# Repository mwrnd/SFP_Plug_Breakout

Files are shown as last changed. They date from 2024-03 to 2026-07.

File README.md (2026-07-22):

**Work-in-Progress** - [First Revision gerbers being tested](https://github.com/mwrnd/SFP_Plug_Breakout/releases/tag/v0.1-alpha).

# SFP_Plug_Breakout

Pluggable [SFP (SFF INF-8074i)](https://members.snia.org/document/dl/26184) and [SFP+ (SFF-8432)](https://members.snia.org/document/dl/25892) Module Breakout for developing SFP modules. PCB must be manufactured with a **1.0mm** thickness.

Similar Projects: [SFP-Breakout-Board](https://github.com/aewallin/SFP-Breakout-Board/tree/df46707f1ecbe9b7fed1791247dec31a45b60560), [SFP_BreakoutBoard](https://github.com/kingyoPiyo/SFP_BreakoutBoard), [SFP-Loopback-Board](https://github.com/aewallin/SFP-Loopback-Board), and [Sfp-breakout](https://osmocom.org/projects/misc-hardware/wiki/Sfp-breakout)(*osmocom.org*).

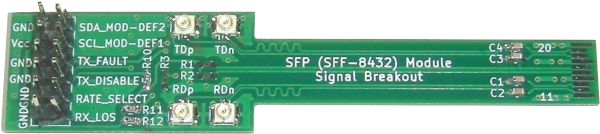
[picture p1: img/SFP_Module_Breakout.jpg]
SFP Module Breakout


One trivial use is an [SFP Loopback](https://www.fs.com/products/109371.html):

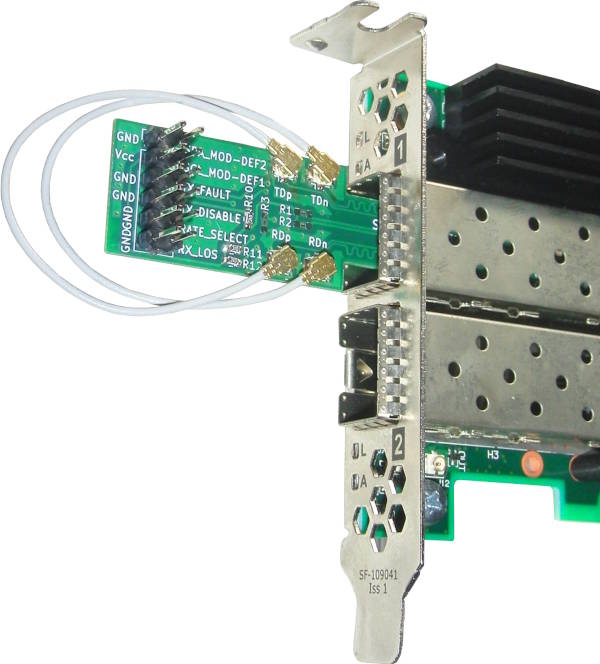
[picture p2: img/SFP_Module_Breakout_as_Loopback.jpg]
SFP Module Breakout as Loopback


## PCB Layout

Differential pair parameters were calculated based on a **board thickness of 1.0mm**.

SFP Plug Module Breakout PCB Layout

## Schematic

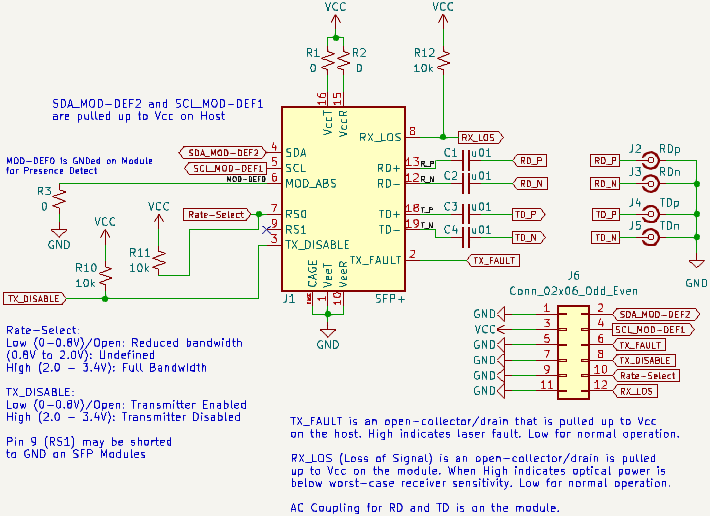
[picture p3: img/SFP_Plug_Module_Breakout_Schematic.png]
SFP Plug Module Breakout Schematic


The 0.1" Header is designed to accept jumpers for the **TX_FAULT**, **RX_LOS**, **TX_DISABLE**, and optionally **Rate-Select** signals.

**TX_FAULT**, **RX_LOS**, and **TX_DISABLE** jumpers need to be mounted for normal operation. These signals are pulled up to Vcc with 10k resistors but are Active-Low.

## Bill Of Materials

I have been testing with general purpose capacitors for the RX and TX DC-Blocking capacitors (C1, C2, C3, C4) but at <10Gbps bitrates. Capacitors will need to be sized smaller, 0402 or even 0201, and more effort would need to go into their selection for high bitrates. Look for [capacitors designed for high-frequency](https://www.digikey.ca/en/products/detail/passive-plus/0402BB104KW500/19186629).

| Designator(s) | Part Number | Quantity | Value | Footprint | Availability |
| --- | --- | --- | --- | --- | --- |
| C1, C2, C3, C4  | GRM1885C1H103JA01D  | 4 | 0.01uF  | Capacitor_SMD:C_0603_1608Metric  | [DigiKey](https://www.digikey.ca/en/products/detail/murata-electronics/GRM1885C1H103JA01D/4421555) |
| R1, R2, R3 | RMCF0603ZT0R00 | 3 | 0-Ohm | Resistor_SMD:R_0603_1608Metric | [DigiKey](https://www.digikey.ca/en/products/detail/stackpole-electronics-inc/RMCF0603ZT0R00/1756908)  |
| R10, R11, R12 | RNCF0603DTE10K0 | 3 | 10k-Ohm | Resistor_SMD:R_0603_1608Metric | [DigiKey](https://www.digikey.ca/en/products/detail/stackpole-electronics-inc/RNCF0603DTE10K0/1708145) |
| J6 | PH2-12-UA | 1 | N/A | Conn_02x06 | [DigiKey](https://www.digikey.ca/en/products/detail/adam-tech/PH2-12-UA/9830397) |
| J2, J3, J4, J5  | CONUFL001-SMD-T | 4 | N/A | U.FL_w_Label:U.FL_Hirose_w_Label | [DigiKey](https://www.digikey.ca/en/products/detail/te-connectivity-linx/CONUFL001-SMD-T/7427732) |
| None | QPC02SXGN-RC | 4 | N/A | 1x2 0.1" Jumper | [DigiKey](https://www.digikey.ca/en/products/detail/sullins-connector-solutions/QPC02SXGN-RC/2618262)  |
| U.FL-to-U.FL | 2015698-2 | 2 | N/A | None - Optional Part for Testing | [DigiKey](https://www.digikey.ca/en/products/detail/te-connectivity-amp-connectors/2015698-2/1249186)  |

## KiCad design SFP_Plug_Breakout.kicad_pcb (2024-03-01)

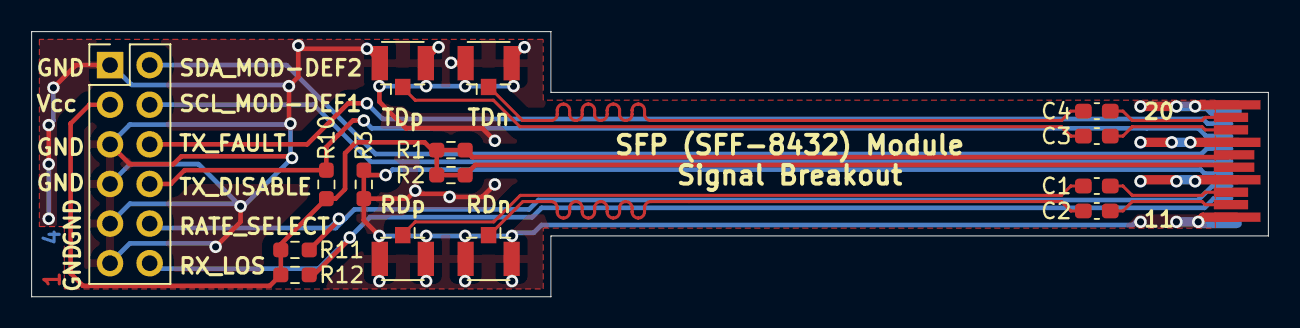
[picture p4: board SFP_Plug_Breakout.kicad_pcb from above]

Board: 4 copper layers, 79.3 x 17.0 mm, 16 parts (0 on the bottom side), 17 nets.

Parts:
C1, C2, C3, C4: u01; C_0603_1608Metric_Pad1.08x0.95mm_HandSolder
J1: SFP+; SFP_Plug
J2: RDp; U.FL_Hirose_w_Label
J3: RDn; U.FL_Hirose_w_Label
J4: TDp; U.FL_Hirose_w_Label
J5: TDn; U.FL_Hirose_w_Label
J6: Conn_02x06_Odd_Even; PinHeader_2x06_P2.54mm_Vertical
R1, R2, R3: 0; R_0603_1608Metric_Pad0.98x0.95mm_HandSolder
R10, R11, R12: 10k; R_0603_1608Metric_Pad0.98x0.95mm_HandSolder

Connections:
/MOD-DEF0: J1.6 (MOD_ABS), R3.1
/R_N: C2.1, J1.12 (RD-)
/R_P: C1.1, J1.13 (RD+)
/T_N: C4.1, J1.19 (TD-)
/T_P: C3.1, J1.18 (TD+)
GND: J1.1 (VeeT), J1.10 (VeeR), J1.11 (VeeR), J1.14 (VeeR), J1.17 (VeeT), J1.20 (VeeT), J2.2 (Ext), J3.2 (Ext), J4.2 (Ext), J5.2 (Ext), J6.1, J6.5, J6.7, J6.9, J6.11, R3.2
RD_N: C2.2, J3.1 (In)
RD_P: C1.2, J2.1 (In)
RX_LOS: J1.8 (RX_LOS), J6.12, R12.2
Rate-Select: J1.7 (RS0), J6.10, R11.2
SCL_MOD-DEF1: J1.5 (SCL), J6.4
SDA_MOD-DEF2: J1.4 (SDA), J6.2
TD_N: C4.2, J5.1 (In)
TD_P: C3.2, J4.1 (In)
TX_DISABLE: J1.3 (TX_DISABLE), J6.8, R10.2
TX_FAULT: J1.2 (TX_FAULT), J6.6
VCC: J1.15 (VccR), J1.16 (VccT), J6.3, R1.1, R1.2, R2.1, R2.2, R10.1, R11.1, R12.1

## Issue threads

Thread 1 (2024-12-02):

BOM and CPL

mluis, 2024-12-02:
Would it be possible to include BOM and CPL files too?

mwrnd, 2024-12-08:
I have [added](https://github.com/mwrnd/SFP_Plug_Breakout/commit/af60a48f79193e28b0fd2d0774512b7ce06a8c83) a [Bill of Materials](https://github.com/mwrnd/SFP_Plug_Breakout?tab=readme-ov-file#bill-of-materials).

I DIY'ed my board. I hand-soldered all the components. The [KiCad Documentation](https://docs.kicad.org/) has [instructions on creating a placement file](https://docs.kicad.org/8.0/en/pcbnew/pcbnew.html#component_placement_files). Some PCB manufacturers also [have instructions](https://www.pcbway.com/blog/help_center/Generate_Position_File_in_Kicad.html).

I am using general purpose capacitors as the DC-blocking caps but testing at low bitrates. More effort may be required to get everything working at 25G. At the very least, the PCB should be manufactured with [Impedance Control](https://jlcpcb.com/impedance).

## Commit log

2024-03-01 First Revision
    [SFP_Plug_Breakout.kicad_pcb, SFP_Plug_Breakout.kicad_sch]
2024-12-08 Added Bill of Materials
